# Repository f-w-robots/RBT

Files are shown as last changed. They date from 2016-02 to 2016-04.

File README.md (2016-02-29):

#### Installation
  - Install Arduino IDE 1.6.7
  - To work with esp8266, install "Arduino core for ESP8266 WiFi chip", [2.1.](https://github.com/esp8266/Arduino)
  - Libraries
    - [ArduinoWebSockets 2.0](https://github.com/Links2004/arduinoWebSockets)(ESP8266)
    - [ArduinoWebsocketClient](https://github.com/f-w-robots/ArduinoWebsocketClient)(WiFiShield)

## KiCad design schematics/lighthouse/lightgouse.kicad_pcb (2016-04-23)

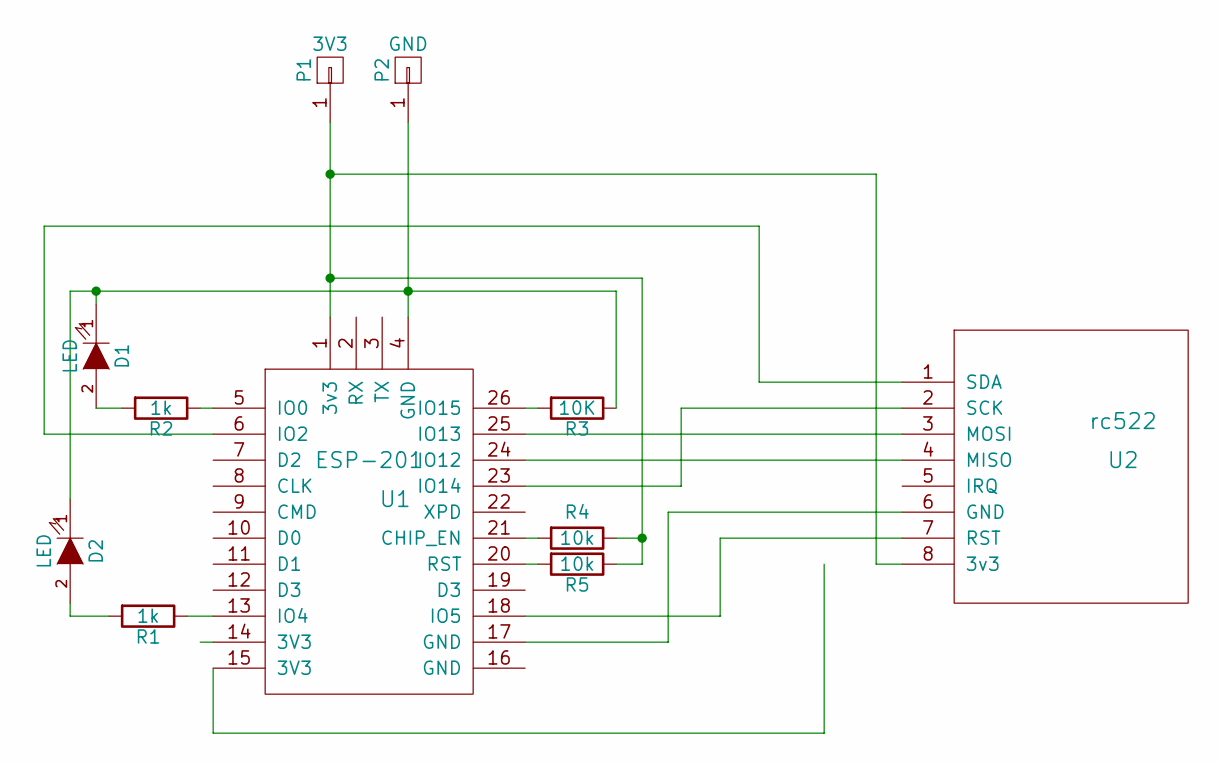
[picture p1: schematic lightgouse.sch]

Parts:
D1, D2: LED; LED-5MM
P1: 3V3; Pin_Header_Straight_1x01
P2: GND; Pin_Header_Straight_1x01
R1, R2: 1k; Resistor_Horizontal_RM7mm
R3: 10K; RC05
R4, R5: 10k; RC05
U1: ESP-201; ESP201
U2: rc522; RC522

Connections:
unnamed: D1.1 (K), D2.1 (K), P2.1, R3.1, U1.4 (GND)
unnamed: D1.2 (A), R2.2
unnamed: D2.2 (A), R1.2
unnamed: P1.1, R4.1, R5.1, U1.1 (3v3), U2.8 (3v3)
unnamed: R1.1, U1.13 (IO4)
unnamed: R2.1, U1.5 (IO0)
unnamed: R3.2, U1.26 (IO15)
unnamed: R4.2, U1.21 (CHIP_EN)
unnamed: R5.2, U1.20 (RST)
unnamed: U1.6 (IO2), U2.1 (SDA)
unnamed: U1.17 (GND), U2.6 (GND)
unnamed: U1.18 (IO5), U2.7 (RST)
unnamed: U1.23 (IO14), U2.2 (SCK)
unnamed: U1.24 (IO12), U2.4 (MISO)
unnamed: U1.25 (IO13), U2.3 (MOSI)

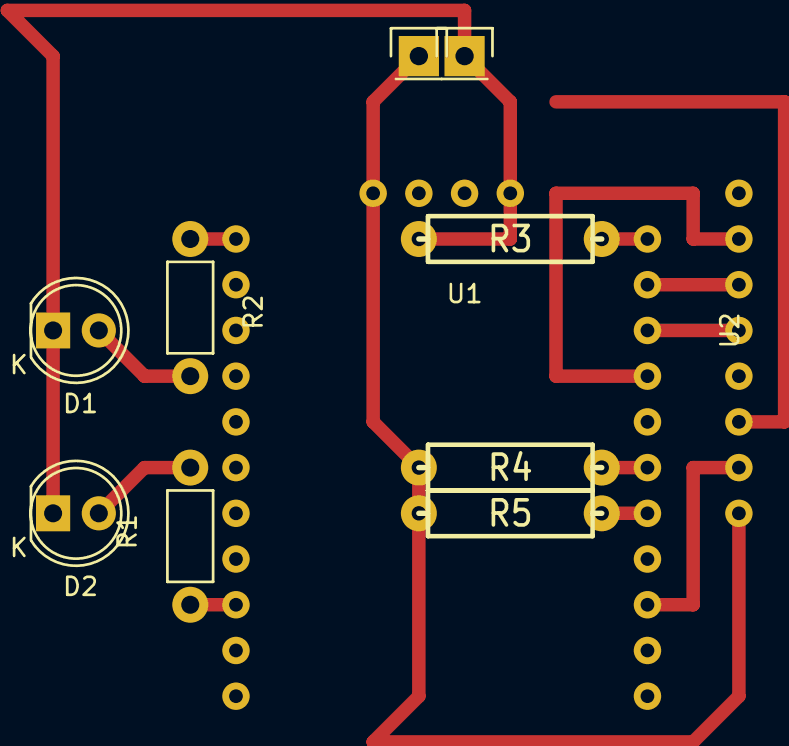
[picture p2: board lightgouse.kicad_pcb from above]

Board: 2 copper layers, 11 parts (0 on the bottom side), 15 nets.

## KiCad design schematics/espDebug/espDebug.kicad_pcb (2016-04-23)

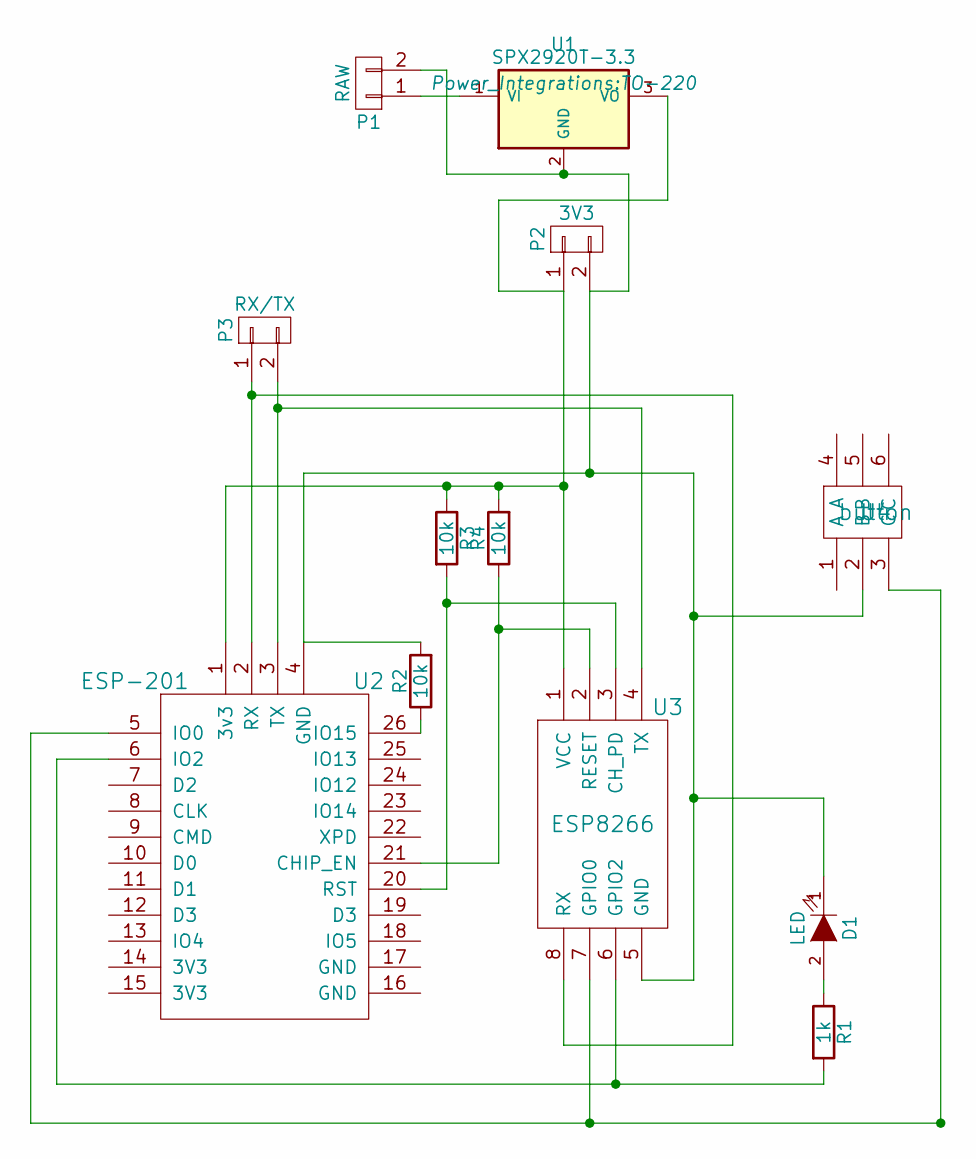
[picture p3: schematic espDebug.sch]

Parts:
D1: LED; LED-3MM
P1: RAW; Pin_Header_Straight_1x02
P2: 3V3; Pin_Header_Straight_1x02
P3: RX/TX; Pin_Header_Straight_1x02
R1: 1k; Resistor_Horizontal_RM7mm
R2, R3, R4: 10k; Resistor_Horizontal_RM7mm
U1: SPX2920T-3.3; TO-220
U2: ESP-201; ESP201
U3: ESP8266; esp8266
U4: button

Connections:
unnamed: D1.1 (K), P1.2, P2.2, R2.2, U1.2 (GND), U2.4 (GND), U3.5 (GND), U4.2 (B)
unnamed: D1.2 (A), R1.1
unnamed: P1.1, U1.1 (VI)
unnamed: P2.1, R3.1, R4.2, U1.3 (VO), U2.1 (3v3), U3.1 (VCC)
unnamed: P3.1, U2.2 (RX), U3.8 (RX)
unnamed: P3.2, U2.3 (TX), U3.4 (TX)
unnamed: R1.2, U2.6 (IO2), U3.6 (GPIO2)
unnamed: R2.1, U2.26 (IO15)
unnamed: R3.2, U2.20 (RST), U3.3 (CH_PD)
unnamed: R4.1, U2.21 (CHIP_EN), U3.2 (RESET)
unnamed: U2.5 (IO0), U3.7 (GPIO0), U4.3 (C)

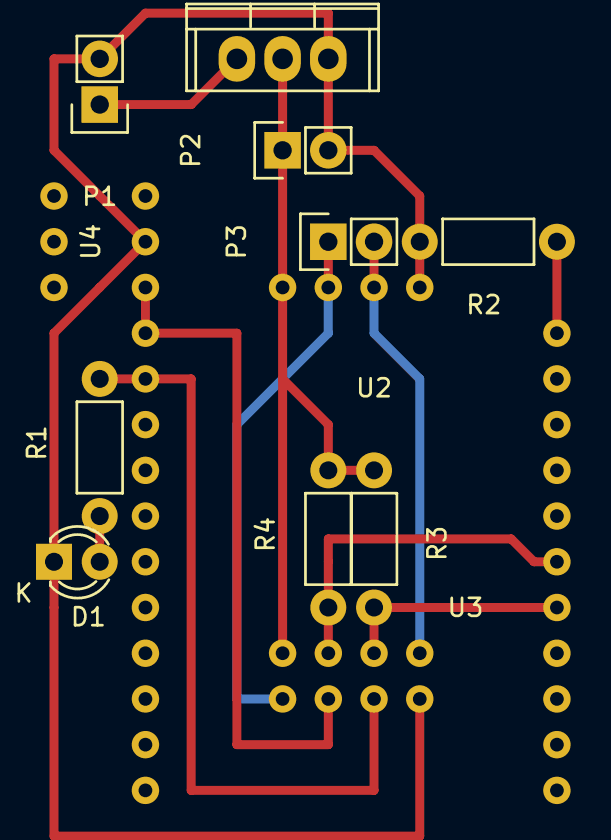
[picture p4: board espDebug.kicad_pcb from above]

Board: 2 copper layers, 12 parts (0 on the bottom side), 11 nets.

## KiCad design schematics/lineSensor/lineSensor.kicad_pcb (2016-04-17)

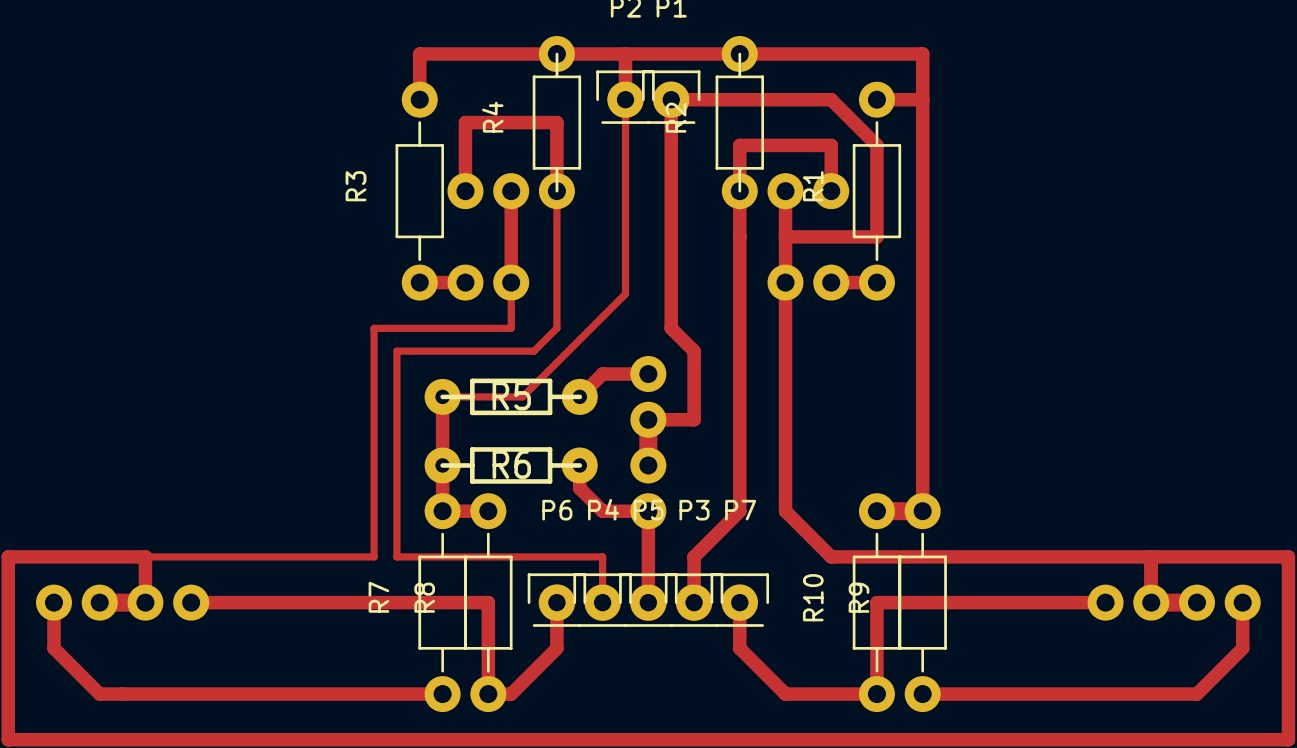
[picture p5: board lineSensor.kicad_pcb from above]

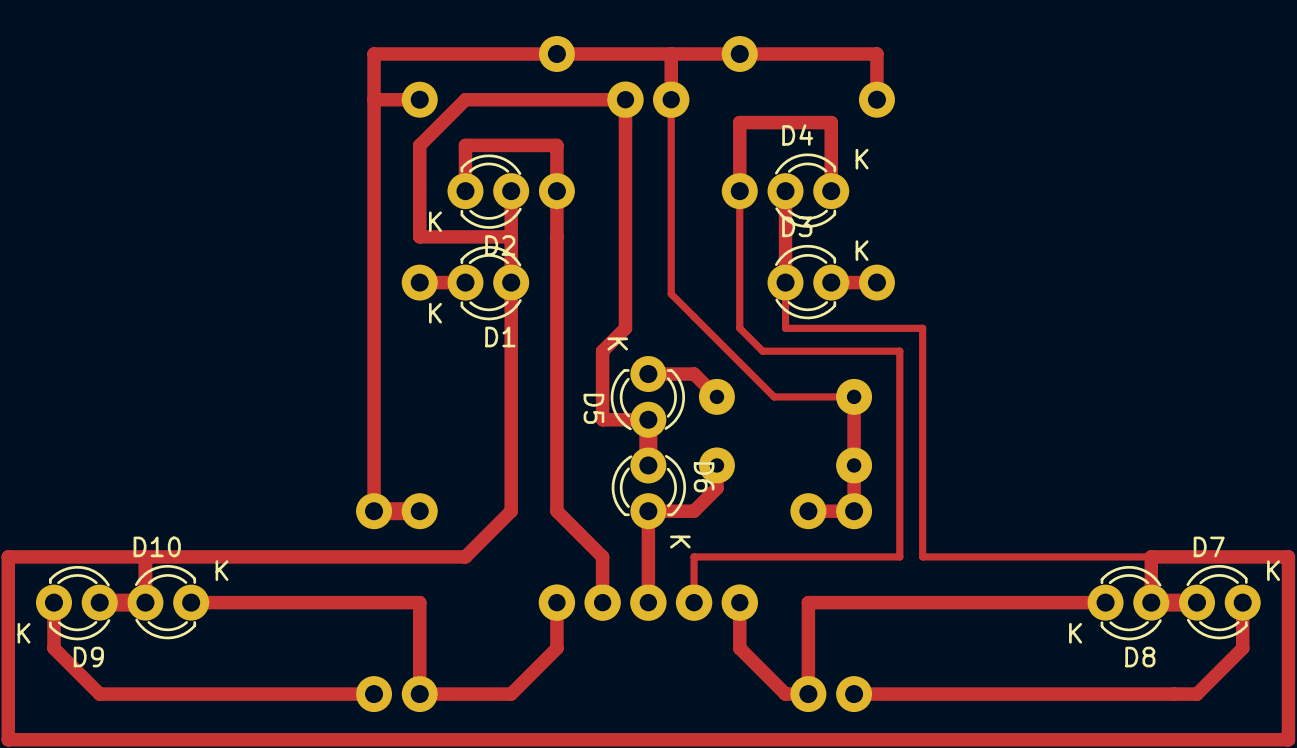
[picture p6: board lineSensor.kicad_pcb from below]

Board: 2 copper layers, 27 parts (10 on the bottom side), 12 nets.

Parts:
D1, D2, D3, D4, D5, D6, D7, D8, D9, D10: LED; LED-3MM
P1, P2, P3, P4, P5, P6, P7: CONN_01X01; Pin_Header_Straight_1x01
R1, R2, R3, R4, R7, R8, R9, R10: R; Resistor_Horizontal_RM10mm
R5, R6: R; RC03

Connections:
unnamed: D1.1, R1.1
unnamed: D1.2, D2.2, D3.2, D4.2, D5.2, D6.2, D7.2, D8.2, D9.2, D10.2, P1.1
unnamed: D2.1, P3.1, R2.1
unnamed: D3.1, R3.1
unnamed: D4.1, P4.1, R4.1
unnamed: D5.1, R5.1
unnamed: D6.1, P5.1, R6.1
unnamed: D7.1, R7.1
unnamed: D8.1, P6.1, R8.1
unnamed: D9.1, R9.1
unnamed: D10.1, P7.1, R10.1
unnamed: P2.1, R1.2, R2.2, R3.2, R4.2, R5.2, R6.2, R7.2, R8.2, R9.2, R10.2

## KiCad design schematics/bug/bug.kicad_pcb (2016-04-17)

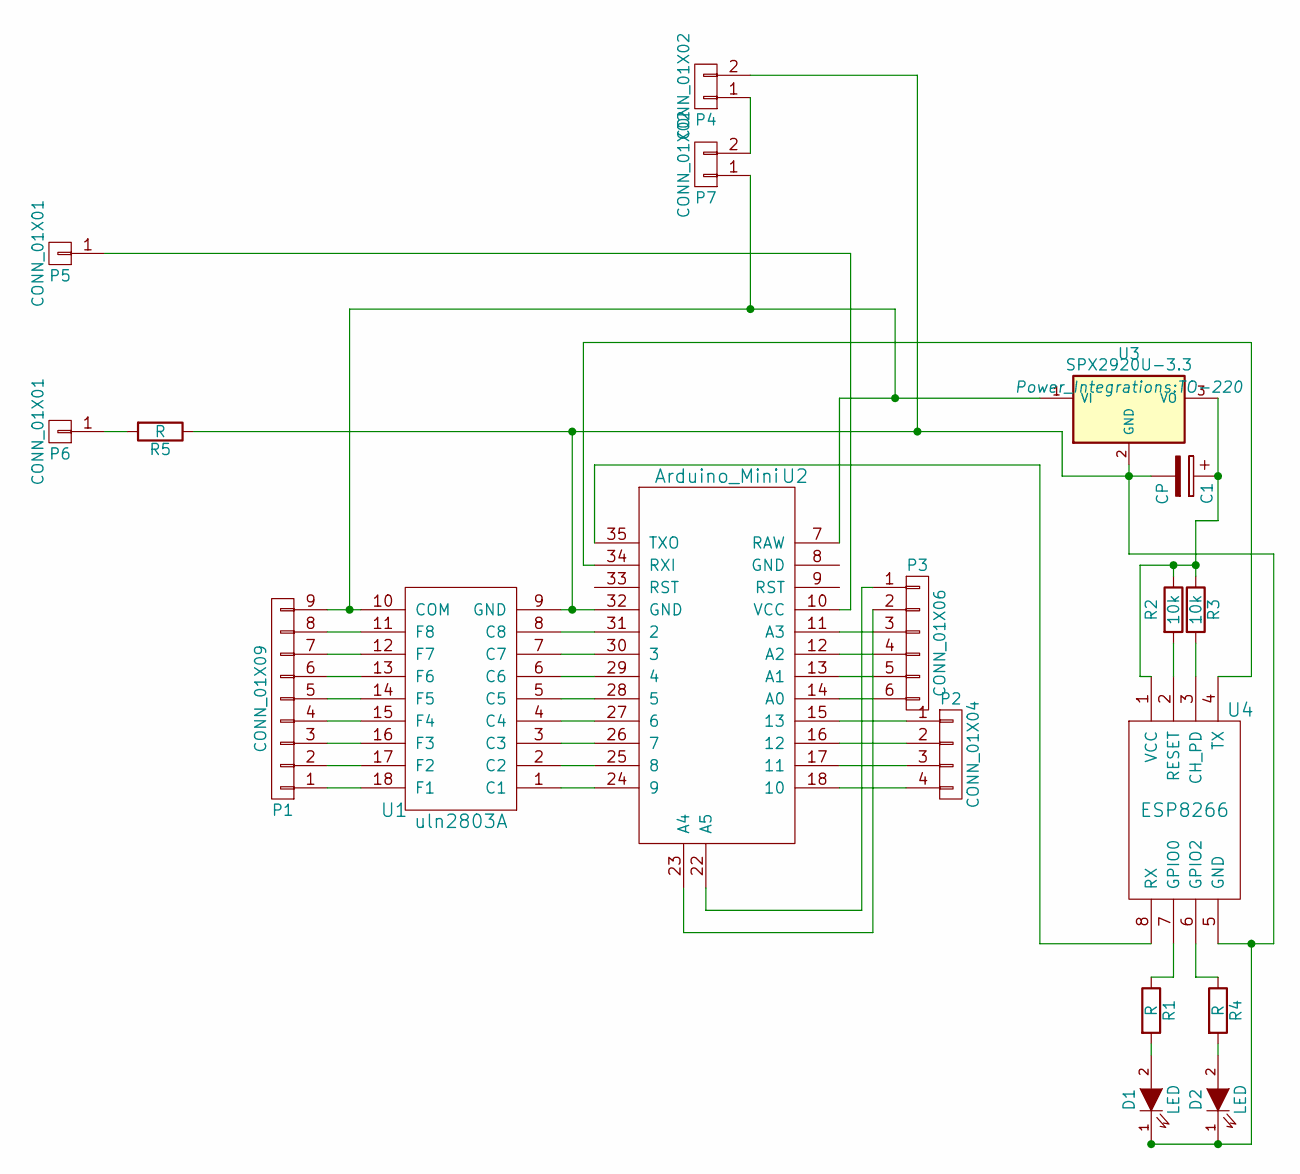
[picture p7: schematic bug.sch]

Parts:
C1: CP; CPR10X16
D1, D2: LED; LED-5MM
P1: CONN_01X09; Pin_Header_Straight_1x09
P2: CONN_01X04; Pin_Header_Straight_1x04
P3: CONN_01X06; Pin_Header_Straight_1x06
P4, P7: CONN_01X02; Pin_Header_Straight_1x02
P5, P6: CONN_01X01; Socket_Strip_Straight_1x01
R1, R4: R; rc05_vert
R2, R3: 10k; rc05_vert
R5: R; Resistor_Horizontal_RM7mm
U1: uln2803A; DIP-18_W7.62mm
U2: Arduino_Mini; arduino_mini_pro
U3: SPX2920U-3.3; TO-220
U4: ESP8266

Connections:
unnamed: C1.1, R2.1, R3.1, U3.3 (VO), U4.1 (VCC)
unnamed: C1.2, D1.1 (K), D2.1 (K), P4.2, R5.1, U1.9 (GND), U2.32 (GND), U3.2 (GND), U4.5 (GND)
unnamed: D1.2 (A), R1.2
unnamed: D2.2 (A), R4.2
unnamed: P1.1, U1.18 (F1)
unnamed: P1.2, U1.17 (F2)
unnamed: P1.3, U1.16 (F3)
unnamed: P1.4, U1.15 (F4)
unnamed: P1.5, U1.14 (F5)
unnamed: P1.6, U1.13 (F6)
unnamed: P1.7, U1.12 (F7)
unnamed: P1.8, U1.11 (F8)
unnamed: P1.9, P7.1, U1.10 (COM), U2.7 (RAW), U3.1 (VI)
unnamed: P2.1, U2.15 (13)
unnamed: P2.2, U2.16 (12)
unnamed: P2.3, U2.17 (11)
unnamed: P2.4, U2.18 (10)
unnamed: P3.1, U2.22 (A5)
unnamed: P3.2, U2.23 (A4)
unnamed: P3.3, U2.11 (A3)
unnamed: P3.4, U2.12 (A2)
unnamed: P3.5, U2.13 (A1)
unnamed: P3.6, U2.14 (A0)
unnamed: P4.1, P7.2
unnamed: P5.1, U2.10 (VCC)
unnamed: P6.1, R5.2
unnamed: R1.1, U4.7 (GPIO0)
unnamed: R2.2, U4.2 (RESET)
unnamed: R3.2, U4.3 (CH_PD)
unnamed: R4.1, U4.6 (GPIO2)
unnamed: U1.1 (C1), U2.24 (9)
unnamed: U1.2 (С2), U2.25 (8)
unnamed: U1.3 (С3), U2.26 (7)
unnamed: U1.4 (С4), U2.27 (6)
unnamed: U1.5 (С5), U2.28 (5)
unnamed: U1.6 (С6), U2.29 (4)
unnamed: U1.7 (С7), U2.30 (3)
unnamed: U1.8 (С8), U2.31 (2)
unnamed: U2.34 (RXI), U4.4 (TX)
unnamed: U2.35 (TXO), U4.8 (RX)

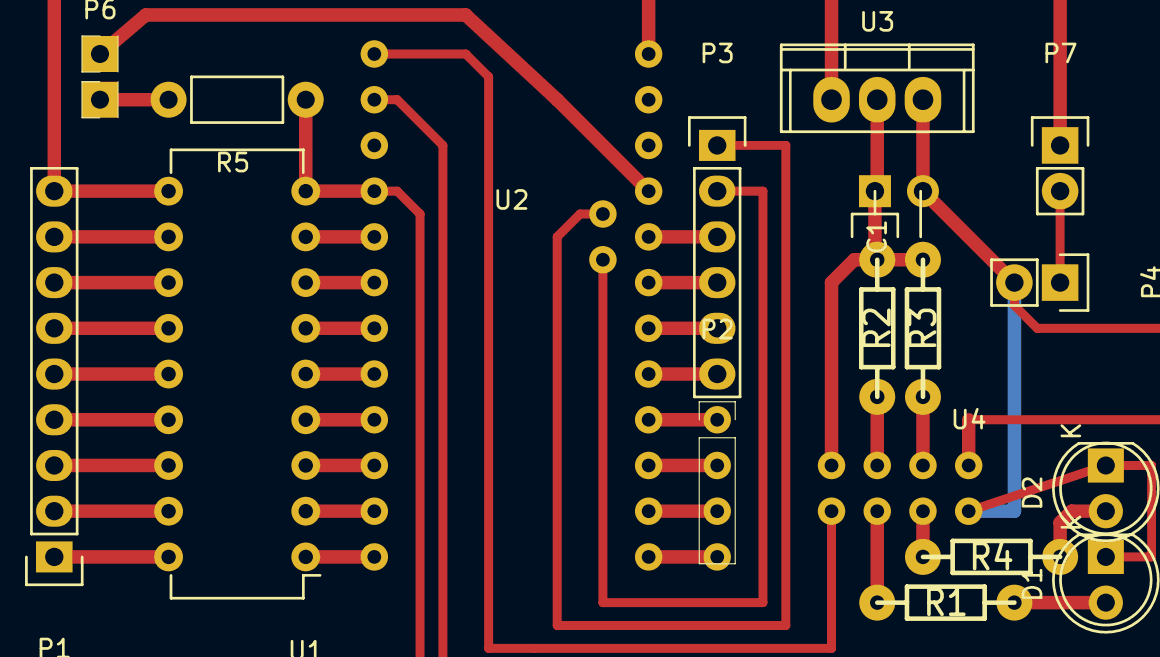
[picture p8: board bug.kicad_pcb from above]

Board: 2 copper layers, 19 parts (0 on the bottom side), 40 nets.

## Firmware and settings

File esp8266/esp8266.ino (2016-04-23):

#include <Arduino.h>
#include <ESP8266WiFi.h>
#include <WebSocketsClient.h>
#include <EEPROM.h>
#include <ESP8266HTTPClient.h>

#define MAX_MSG_LEN 256

#define PIN_LED_WIFI 2
#define PIN_LED_SOCKET 0

boolean pin_led_socket_value = LOW;

int8_t status = 0;

WebSocketsClient webSocket;

const char SYS_SSID[] = "kernel";
const char SYS_PASS[] = "axtr456E";

char *ssid;
char *password;

char *host;
const uint16_t port = 2500;
char *url;

const uint16_t wifiBlinkDelay = 50;

void webSocketEvent(WStype_t type, uint8_t *payload, size_t lenght) {
  switch (type) {
    case WStype_DISCONNECTED:
      if (status) {
        digitalWrite(PIN_LED_WIFI, HIGH);
        digitalWrite(PIN_LED_SOCKET, HIGH);
      }
      break;
    case WStype_CONNECTED:
      status = 1;
      digitalWrite(PIN_LED_WIFI, LOW);
      digitalWrite(PIN_LED_SOCKET, HIGH);
      Serial.write(29);
      break;
    case WStype_TEXT:
      for (int i = 0; lenght != i; i++)
        Serial.write(payload[i]);
      break;
    case WStype_BIN:
      for (int i = 0; lenght != i; i++)
        Serial.write(payload[i]);
      break;
  }
}

uint8_t connectToWiFi(const char* ssid, const char* pass) {
  WiFi.begin(ssid, pass);

  while (WiFi.status() != WL_CONNECTED) {
    delay(wifiBlinkDelay);
    digitalWrite(PIN_LED_WIFI, LOW);
    delay(wifiBlinkDelay);
    digitalWrite(PIN_LED_WIFI, HIGH);
    if (WiFi.status() == WL_CONNECT_FAILED || WiFi.status() == WL_NO_SSID_AVAIL) {
      int status = WiFi.status();
      WiFi.disconnect();
      return status;
    }
  }
  return WiFi.status();
}

void loadConfig() {
  ssid = new char[32];
  for (int i = 0; i < 32; i++) {
    ssid[i] = EEPROM.read(i);
  }
  password = new char[32];
  for (int i = 32; i < 64; i++) {
    password[i - 32] = EEPROM.read(i);
  }
  host = new char[32];
  for (int i = 64; i < 96; i++) {
    host[i - 64] = EEPROM.read(i);
  }
  url = new char[32];
  for (int i = 96; i < 128; i++) {
    url[i - 96] = EEPROM.read(i);
  }
}

void updateConfig() {
  while (WiFi.status() != WL_CONNECTED) {
    connectToWiFi(SYS_SSID, SYS_PASS);
  }
  HTTPClient http;
  char* payload = new char[32];

  http.begin("http://192.168.4.1/ssid.txt");
  http.GET();
  http.getString().toCharArray(payload, 32);
  writeConfig(0, payload, strlen(payload));
  http.begin("http://192.168.4.1/pass");
  http.GET();
  http.getString().toCharArray(payload, 32);
  writeConfig(1, payload, strlen(payload));
  http.begin("http://192.168.4.1/host");
  http.GET();
  http.getString().toCharArray(payload, 32);
  writeConfig(2, payload, strlen(payload));

  EEPROM.commit();
  WiFi.disconnect();
}

void writeConfig(uint8_t i, char* data, uint8_t length) {
  int j = 0;
  for (; j < 32 && j < length; j++) {
    EEPROM.write(i * 32 + j, data[j]);
  }
  EEPROM.write(i * 32 + j, 0);
}

void setup() {
  WiFi.softAPdisconnect(true);

  pinMode(PIN_LED_WIFI, OUTPUT);
  pinMode(PIN_LED_SOCKET, OUTPUT);
  digitalWrite(PIN_LED_WIFI, HIGH);
  digitalWrite(PIN_LED_SOCKET, LOW);

  Serial.begin(115200);
  delay(10);

  EEPROM.begin(512);
  loadConfig();

  while (WiFi.status() != WL_CONNECTED) {
    int status = connectToWiFi(ssid, password);
    if (status == WL_NO_SSID_AVAIL) {
      updateConfig();
      loadConfig();
    }
  }

  webSocket.begin(host, port, url);
  webSocket.onEvent(webSocketEvent);
}

int packageLen = 0;
int packageI = 0;
char package[256];

void readPackages() {
  if (Serial.available() > 0) {
    if (packageLen == 0) {
      packageLen = Serial.read();
    } else {
      package[packageI] = Serial.read();
      packageI++;
      if (packageI == packageLen) {
        webSocket.sendTXT(package, packageLen);
        packageLen = 0;
        packageI = 0;
      }
    }
  }
}

void loop() {
  webSocket.loop();
  readPackages();
}

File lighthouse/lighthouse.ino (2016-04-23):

#include <Arduino.h>
#include <ESP8266WiFi.h>
#include <WebSocketsClient.h>
#include <EEPROM.h>
#include <ESP8266WebServer.h>

#include "DeviceRC522.h"

#define MAX_MSG_LEN 256

DeviceRC522 *device = NULL;

ESP8266WebServer server(80);

boolean pin_led_socket_value = LOW;

WebSocketsClient webSocket;

char *ssid;
char *password;

char *host;
const uint16_t port = 2500;
char *url;

const uint16_t wifiBlinkDelay = 50;

void webSocketEvent(WStype_t type, uint8_t *payload, size_t lenght) {
  switch (type) {
    case WStype_DISCONNECTED:
      break;
    case WStype_CONNECTED:
      break;
    case WStype_TEXT:
      for (int i = 0; lenght != i; i++)
        Serial.write(payload[i]);
      break;
    case WStype_BIN:
      for (int i = 0; lenght != i; i++)
        Serial.write(payload[i]);
      break;
  }
}

uint8_t connectToWiFi(const char* ssid, const char* pass) {
  WiFi.begin(ssid, pass);

  while (WiFi.status() != WL_CONNECTED) {
    delay(100);
    if (WiFi.status() == WL_CONNECT_FAILED || WiFi.status() == WL_NO_SSID_AVAIL) {
      int status = WiFi.status();
      WiFi.disconnect();
      return status;
    }
  }
  return WiFi.status();
}

void loadConfig() {
  ssid = new char[32];
  for (int i = 0; i < 32; i++) {
    ssid[i] = EEPROM.read(i);
  }
  password = new char[32];
  for (int i = 32; i < 64; i++) {
    password[i - 32] = EEPROM.read(i);
  }
  host = new char[32];
  for (int i = 64; i < 96; i++) {
    host[i - 64] = EEPROM.read(i);
  }
  url = new char[32];
  for (int i = 96; i < 128; i++) {
    url[i - 96] = EEPROM.read(i);
  }
}

void writeConfig(uint8_t i, char* data, uint8_t length) {
  int j = 0;
  for (; j < 32 && j < length; j++) {
    EEPROM.write(i * 32 + j, data[j]);
  }
  EEPROM.write(i * 32 + j, 0);
}

void startServer() {
  Serial.println("Start server");
  server.on("/ssid", [](){
    Serial.println("FFF");
    server.send(200, "text/plain", ssid);
  });

  server.on("/password", [](){
    server.send(200, "text/plain", password);
  });

  server.on("/host", [](){
    server.send(200, "text/plain", host);
  });

  server.on("/", HTTP_GET, [](){
    server.sendHeader("Connection", "close");
    server.sendHeader("Access-Control-Allow-Origin", "*");
    server.send ( 200, "text/html", "<html>\
      <head>\
        <title>Configure</title>\
        <style>\
          body { background-color: #cccccc; font-family: Arial, Helvetica, Sans-Serif; Color: #000088; }\
        </style>\
      </head>\
      <body>\
        <h1>Please enter you router config!</h1>\
        <form action='/' method='POST'>\
          SSID:<br>\
          <input type='text' name='ssid'><br>\
          PASSWORD:<br>\
          <input type='password' name='password'><br>\
          <input type='submit'>\
        </form>\
      </body>\
      </html>");
   });

   server.on("/", HTTP_POST, [](){
    if (server.hasArg("ssid") && server.hasArg("password")){
      char* payload = new char[32];
      server.arg("ssid").toCharArray(payload, 32);
      writeConfig(0, payload, 32);
      server.arg("password").toCharArray(payload, 32);
      writeConfig(1, payload, 32);
    }
    server.sendHeader("Connection", "close");
    server.sendHeader("Access-Control-Allow-Origin", "*");
    server.send ( 200, "text/html", "all_saved");
   });

  server.begin();
  Serial.println("server.begin();");
}

void setup() {
  WiFi.softAPdisconnect(true);

  Serial.begin(115200);
  delay(10);

  device = new DeviceRC522(2, 4);

  EEPROM.begin(512);
  loadConfig();
  Serial.println("config loaded");
  while (WiFi.status() != WL_CONNECTED) {
    connectToWiFi(ssid, password);
  }

  startServer();

  webSocket.begin(host, port, url);
  webSocket.onEvent(webSocketEvent);
}

int packageLen = 0;
int packageI = 0;
char package[256];
char c;

void readPackages() {
  if (Serial.available() > 0) {
    c = Serial.read();
    if (packageLen == 0) {
      packageLen = c;
    } else {
      package[packageI] = c;
      packageI++;
      if (packageI == packageLen) {
        webSocket.sendTXT(package, packageLen);
        packageLen = 0;
        packageI = 0;
      }
    }
  }
}

void checkInternalVirtualDevice() {
  if (device != NULL) {
    device->tick();
    if (device->newData()) {
      webSocket.sendTXT(device->readData(), 4);
    }
  }
}

void loop() {
  webSocket.loop();
  server.handleClient();
  readPackages();
  checkInternalVirtualDevice();
}

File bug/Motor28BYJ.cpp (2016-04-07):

#include <Arduino.h>
#include "Motor28BYJ.h"

Motor28BYJ::Motor28BYJ(uint8_t pin1, uint8_t pin2, uint8_t pin3, uint8_t pin4) {
  _pins[0] = pin1;
  _pins[1] = pin2;
  _pins[2] = pin3;
  _pins[3] = pin4;

  for (int i = 0; i < 4; i++) {
    pinMode(this->_pins[i], OUTPUT);
  }
}

void Motor28BYJ::step(int direction) {
  if (direction == 0) {
    for (int pin = 0; pin < 4; pin++) {
      digitalWrite(_pins[pin], LOW);
    }
    return;
  }
  for (int pin = 0; pin < 4; pin++) {
    digitalWrite(_pins[pin], _sequence[(direction > 0 ? position : 3 - position)][pin]);
  }
  position ++;
  if (position > 3)
    position = 0;
}

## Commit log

2016-02-24 Move the arduino code here
2016-02-28 Use Stepper Motors as engines
2016-02-29 Update Arduino for ESP and esp websockets libraries
2016-02-29 Use step engines for ultrasonicx
2016-02-29 Update ultrasonic code for stepper motor
2016-02-29 Separate sketch for stepper car motor car
2016-02-29 ultrasonicStepper follow for line
2016-02-29 ESP8266 for ultrasonicStepper
2016-03-03 Ultrasonic by new protocol
2016-03-03 Stepper support in ultrasonicI2C
2016-03-03 Full messages exchange on i2c support
2016-03-04 Add LED indication to esp8266 I2C
2016-03-04 Optimize ultrasonicI2C code
2016-03-05 Add code for calibration sensors
2016-03-05 Fix stop bug in 28byj
    [Motor28BYJ.cpp]
2016-03-05 Fix direction and sensors reading in car
2016-03-05 Fix bug on sensors reading
2016-03-11 Added commands for calibration
2016-03-11 Remove unnesessary println
2016-03-16 Schema for LineSensors
    [lineSensor.kicad_pcb, lineSensor.sch]
2016-03-16 Update LineSensor schematic
    [lineSensor.kicad_pcb, lineSensor.sch]
2016-03-18 Add ESP8266 schematic
    [esp8266.kicad_pcb, esp8266.sch, lineSensor.kicad_pcb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]
2016-03-22 Update eps8266 schematic
    [esp8266.kicad_pcb]
2016-03-22 Remove cd4051 from sensors and add led debug to arduino
2016-03-24 Fix calibration bug
2016-03-24 Added schematic for bug
    [bug.kicad_pcb, bug.sch]
2016-03-29 Sensors+ESP+Arduino schematic
    [bug.kicad_pcb, bug.sch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]
2016-04-02 set input pins for BUG
    [bug.ino]
2016-04-02 Update schematic lineSensor and bug
    [bug.kicad_pcb, bug.sch, lineSensor.kicad_pcb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]
2016-04-04 SCHEMATICS: group output pins
    [lineSensor.kicad_pcb]
2016-04-04 SCHEMATICS: move arduino A4 and A5 pins
    [bug.kicad_pcb]
2016-04-05 BUG: fix bug with left wheel
    [bug.ino]
2016-04-05 BUG: fix electricity consumption on stop
    [Motor28BYJ.cpp, bug.ino]
2016-04-07 Support for arduino 3v3 and simplify MotorDriver code
2016-04-07 SCHEMATIC: move button and led to one place
    [bug.kicad_pcb, bug.sch]
2016-04-08 SCHEMATIC: update lineSensors and bug
    [bug.kicad_pcb, bug.sch, lineSensor.kicad_pcb]
2016-04-09 Cleanup repository
    [bug.kicad_pcb, bug.sch, esp8266.kicad_pcb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]
2016-04-12 BUG: change debug led13 appointment
    [I2C.cpp, bug.ino]
2016-04-13 Rewrite lineSensors scheme and small update bug
    [bug.kicad_pcb, lineSensor.kicad_pcb]
2016-04-14 Fix esp8266 not response bug
    [esp8266.ino]
2016-04-17 Update schematic
    [bug.kicad_pcb, bug.sch, lineSensor.kicad_pcb]
2016-04-21 SCHEMATIC: create scheme lighthouse
    [lightgouse.kicad_pcb, lightgouse.sch]
2016-04-23 espDebug scheme
    [espDebug.kicad_pcb, espDebug.sch]
2016-04-23 lighthouse scheme
    [lightgouse.kicad_pcb, lightgouse.sch]
